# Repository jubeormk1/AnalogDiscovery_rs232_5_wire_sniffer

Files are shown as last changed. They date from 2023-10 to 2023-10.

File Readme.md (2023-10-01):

# Analog Discovery RS-232 five wire sniffer add on circuit
## Motivation
While troubleshooting an old but extremely robust threadmill, I came across an RS-232 data link between the device and its master computer. Since I do not have any instruments to sniff the messages flowing through a RS-232 link, I decided to build an extension board to add this capability to my Analog Discovery II instrument (AD). To give myself more flexibility, I am adding plenty of headers to monitor extra signal lines in addition to the main RxD and TxD. A total of five lines can be monitored at any time.

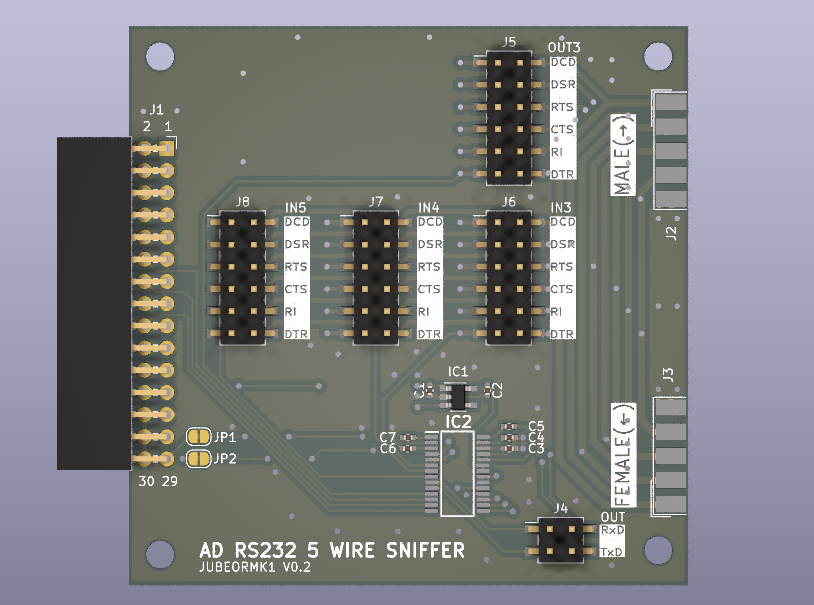
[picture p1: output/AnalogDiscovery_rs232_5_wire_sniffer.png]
Board render

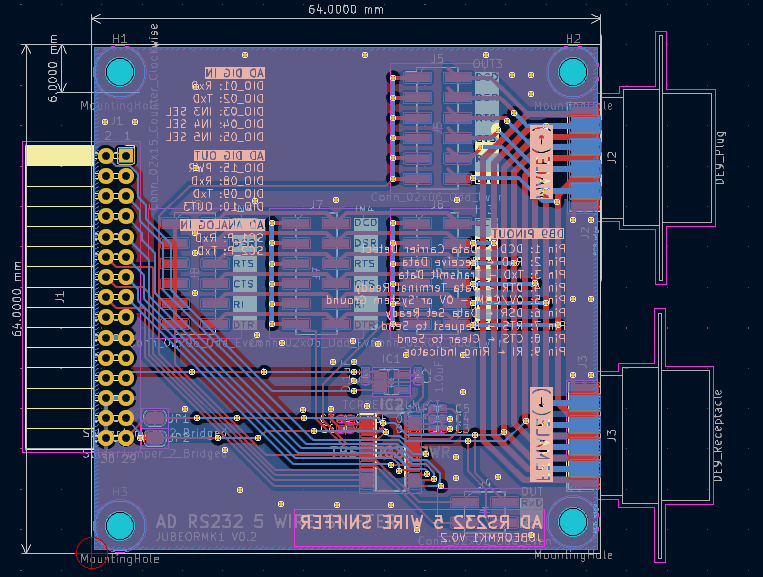
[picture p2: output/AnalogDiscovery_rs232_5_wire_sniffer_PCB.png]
PCB screenshot


## Warnings
Use it at your own risk. I take no responsibility for any damage caused to any device attached to this board. Since this is an experimental circuit, I assume that whoever is reading this is a tinker and has basic skills dealing with extra-low-voltage circuits.

## Features
* Uses the [Texas Instrument TRSF3243EIPWR Multichannel RS-232 compatible line driver/receiver](https://www.ti.com/product/TRSF3243E)
* Five channel RS-232 sniffer
* Passthrough DB9 Male to DB9 female
* RxD and TxD lines always connected to AD instrument ``DIO[0:1]``
* Selectable signals can be connected to the AD ``DIO[2:4]`` via header shunt pins
* RxD and TxD signals connected to AD instrument oscilloscope channels
* Optionally, RxD and TxD can be driven by an AD instrument using ``DIO[8:9]``
* It is also possible to select one more signal line to be driven by an AD instrument ``DIO[10]``
* The driver power can be enable(disable) driving the ``DIO[15]`` high(low)

## Required equipment:
* A data link with RS-232 communication to sniff on
* Personal Computer
* Digilent Analog Discovery (R) Instrument
* Software Digilent Waveforms(R)
* Some extra db9 terminated cables to make the connections

## License

Analog Discovery (R) and Waveforms(R) are Digilent trademarks.
The license is described in the file 'LICENSE'.

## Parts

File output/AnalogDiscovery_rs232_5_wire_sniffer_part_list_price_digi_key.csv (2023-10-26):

Index | Quantity | Part Number | Manufacturer Part Number | Description | Customer Reference | Available | Backorder | Unit Price | Extended Price AUD
1 | 5 | 296-TRSF3243EIPWRCT-ND | TRSF3243EIPWR | IC TRANSCEIVER FULL 3/5 28TSSOP |  | 5 | 0 | 4.64000 | 23.20
2 | 10 | TCR2EF33LM(CTCT-ND | TCR2EF33,LM(CT | IC REG LINEAR 3.3V 200MA SMV |  | 10 | 0 | 0.39300 | 3.93
3 | 100 | 478-KGM05AR71C104KHCT-ND | KGM05AR71C104KH | CAP CER 0.1UF 16V X7R 0402 |  | 100 | 0 | 0.00990 | 0.99
4 | 6 | 718-1719-1-ND | 298D105X0010K2T | CAP TANT 1UF 20% 10V 0402 |  | 6 | 0 | 2.61000 | 15.66
5 | 6 | AE11063-ND | A-DF 09 LL/Z | CONN D-SUB RCPT 9POS SLDR CUP |  | 6 | 0 | 0.84000 | 5.04
6 | 6 | AE10972-ND | A-DS 09 LL/Z | CONN D-SUB PLUG 9POS SLDR CUP |  | 6 | 0 | 0.84000 | 5.04
7 | 6 | 4324-PHDD-SS004G1ABOGE-B005CT-ND | PHDD-SS004G1ABOGE-B005 | MALE HEADER VERTICAL SMD 4POS G/ |  | 6 | 0 | 0.47000 | 2.82
8 | 22 | 4324-PHDD-SS016G1ABOGE-B005CT-ND | PHDD-SS016G1ABOGE-B005 | MALE HEADER VERTICAL SMD 16POS G |  | 22 | 0 | 0.78000 | 17.16
9 | 30 | S9341-ND | NPC02SXON-RC | CONN JUMPER SHORTING .100" GOLD |  | 30 | 0 | 0.11440 | 3.43

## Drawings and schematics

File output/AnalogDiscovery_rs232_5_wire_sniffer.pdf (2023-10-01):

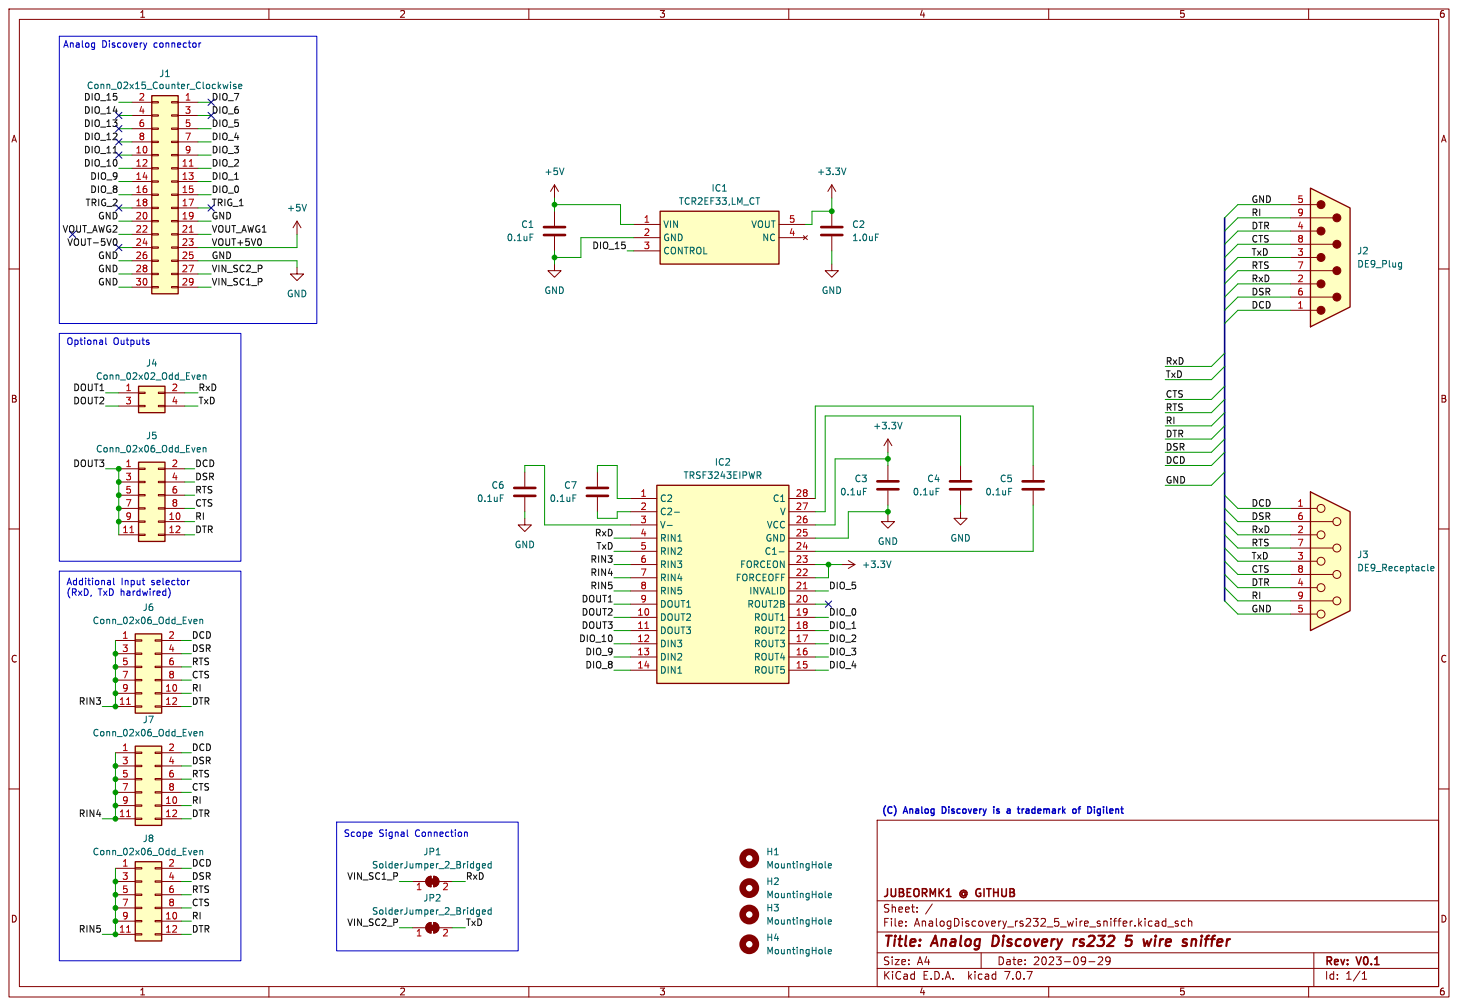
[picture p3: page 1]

CTS GND GND GND GND

(C) Analog Discovery is a trademark of Digilent

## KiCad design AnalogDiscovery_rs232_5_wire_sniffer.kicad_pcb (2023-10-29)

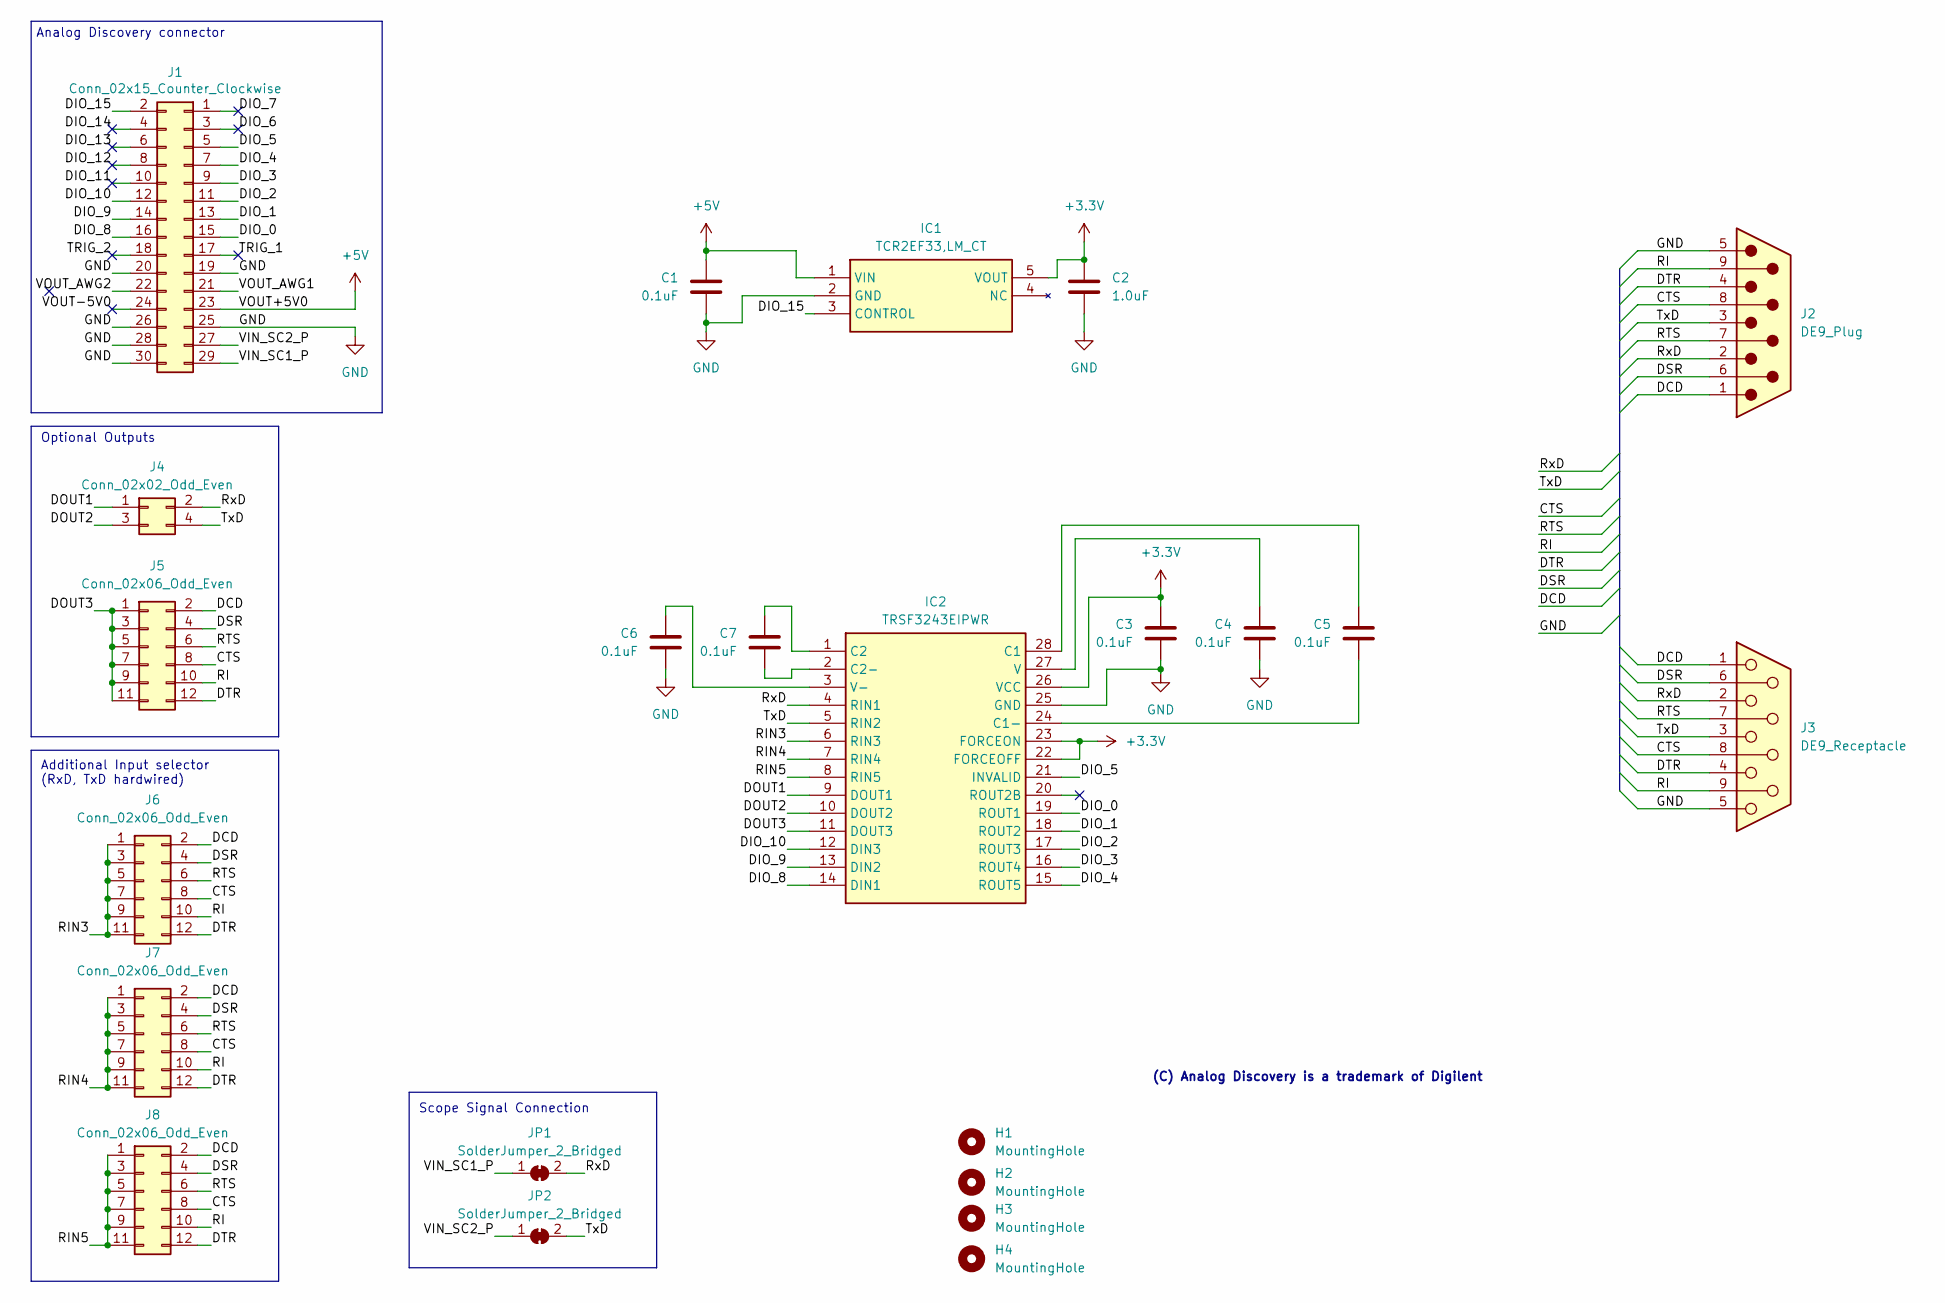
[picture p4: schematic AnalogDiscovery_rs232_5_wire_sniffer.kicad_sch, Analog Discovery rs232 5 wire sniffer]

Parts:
C1, C3, C4, C5, C6, C7: 0.1uF; C_0402_1005Metric_Pad0.74x0.62mm_HandSolder; Manufacturer_Part_Number KGM05AR71C103KH
C2: 1.0uF; C_0603_1608Metric_Pad1.08x0.95mm_HandSolder; Manufacturer_Part_Number KGM05AR71C104KH
H1, H2, H3, H4: MountingHole; MountingHole_3.2mm_M3
IC1: TCR2EF33,LM_CT; SOT-23-5_HandSoldering; Manufacturer_Part_Number TCR2EF33,LM(CT; Mouser Part Number 757-TCR2EF33LMCT
IC2: TRSF3243EIPWR; SOP65P640X120-28N; Manufacturer_Part_Number TRSF3243EIPWR; Mouser Part Number 595-TRSF3243EIPWR
J1: Conn_02x15_Counter_Clockwise; PinSocket_2x15_P2.54mm_Horizontal
J2: DE9_Plug; DSUB-9_Female_EdgeMount_P2.77mm
J3: DE9_Receptacle; DSUB-9_Male_EdgeMount_P2.77mm
J4: Conn_02x02_Odd_Even; PinHeader_2x02_P2.54mm_Vertical_SMD
J5, J6, J7, J8: Conn_02x06_Odd_Even; PinHeader_2x06_P2.54mm_Vertical_SMD
JP1, JP2: SolderJumper_2_Bridged; SolderJumper-2_P1.3mm_Bridged_RoundedPad1.0x1.5mm

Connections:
+3.3V: C2.1, C3.2, IC1.5 (VOUT), IC2.22 (FORCEOFF), IC2.23 (FORCEON), IC2.26 (VCC)
+5V: C1.2, IC1.1 (VIN), J1.23
/CTS: J2.8, J3.8, J5.8, J6.8, J7.8, J8.8
/DCD: J2.1, J3.1, J5.2, J6.2, J7.2, J8.2
/DIO_0: IC2.19 (ROUT1), J1.15
/DIO_1: IC2.18 (ROUT2), J1.13
/DIO_2: IC2.17 (ROUT3), J1.11
/DIO_3: IC2.16 (ROUT4), J1.9
/DIO_4: IC2.15 (ROUT5), J1.7
/DIO_5: IC2.21 (INVALID), J1.5
/DIO_6: J1.3
/DIO_7: J1.1
/DIO_8: IC2.14 (DIN1), J1.16
/DIO_9: IC2.13 (DIN2), J1.14
/DIO_10: IC2.12 (DIN3), J1.12
/DIO_11: J1.10
/DIO_12: J1.8
/DIO_13: J1.6
/DIO_14: J1.4
/DIO_15: IC1.3 (CONTROL), J1.2
/DOUT1: IC2.9 (DOUT1), J4.1
/DOUT2: IC2.10 (DOUT2), J4.3
/DOUT3: IC2.11 (DOUT3), J5.1, J5.3, J5.5, J5.7, J5.9, J5.11
/DSR: J2.6, J3.6, J5.4, J6.4, J7.4, J8.4
/DTR: J2.4, J3.4, J5.12, J6.12, J7.12, J8.12
/RI: J2.9, J3.9, J5.10, J6.10, J7.10, J8.10
/RIN3: IC2.6 (RIN3), J6.1, J6.3, J6.5, J6.7, J6.9, J6.11
/RIN4: IC2.7 (RIN4), J7.1, J7.3, J7.5, J7.7, J7.9, J7.11
/RIN5: IC2.8 (RIN5), J8.1, J8.3, J8.5, J8.7, J8.9, J8.11
/RTS: J2.7, J3.7, J5.6, J6.6, J7.6, J8.6
/RxD: IC2.4 (RIN1), J2.2, J3.2, J4.2, JP1.2 (B)
/TRIG_1: J1.17
/TRIG_2: J1.18
/TxD: IC2.5 (RIN2), J2.3, J3.3, J4.4, JP2.2 (B)
/VIN_SC1_P: J1.29, JP1.1 (A)
/VIN_SC2_P: J1.27, JP2.1 (A)
/VOUT-5V0: J1.24
/VOUT_AWG1: J1.21
/VOUT_AWG2: J1.22
GND: C1.1, C2.2, C3.1, C4.1, C6.1, IC1.2 (GND), IC2.25 (GND), J1.19, J1.20, J1.25, J1.26, J1.28, J1.30, J2.5, J3.5
unnamed: C5.2, IC2.28 (C1)
unnamed: C5.1, IC2.24 (C1-)
unnamed: C7.2, IC2.1 (C2)
unnamed: C7.1, IC2.2 (C2-)
unnamed: C4.2, IC2.27 (V)
unnamed: C6.2, IC2.3 (V-)

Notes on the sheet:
Scope Signal Connection
Analog Discovery connector
Optional Outputs
Additional Input selector (RxD, TxD hardwired)
(C) Analog Discovery is a trademark of Digilent

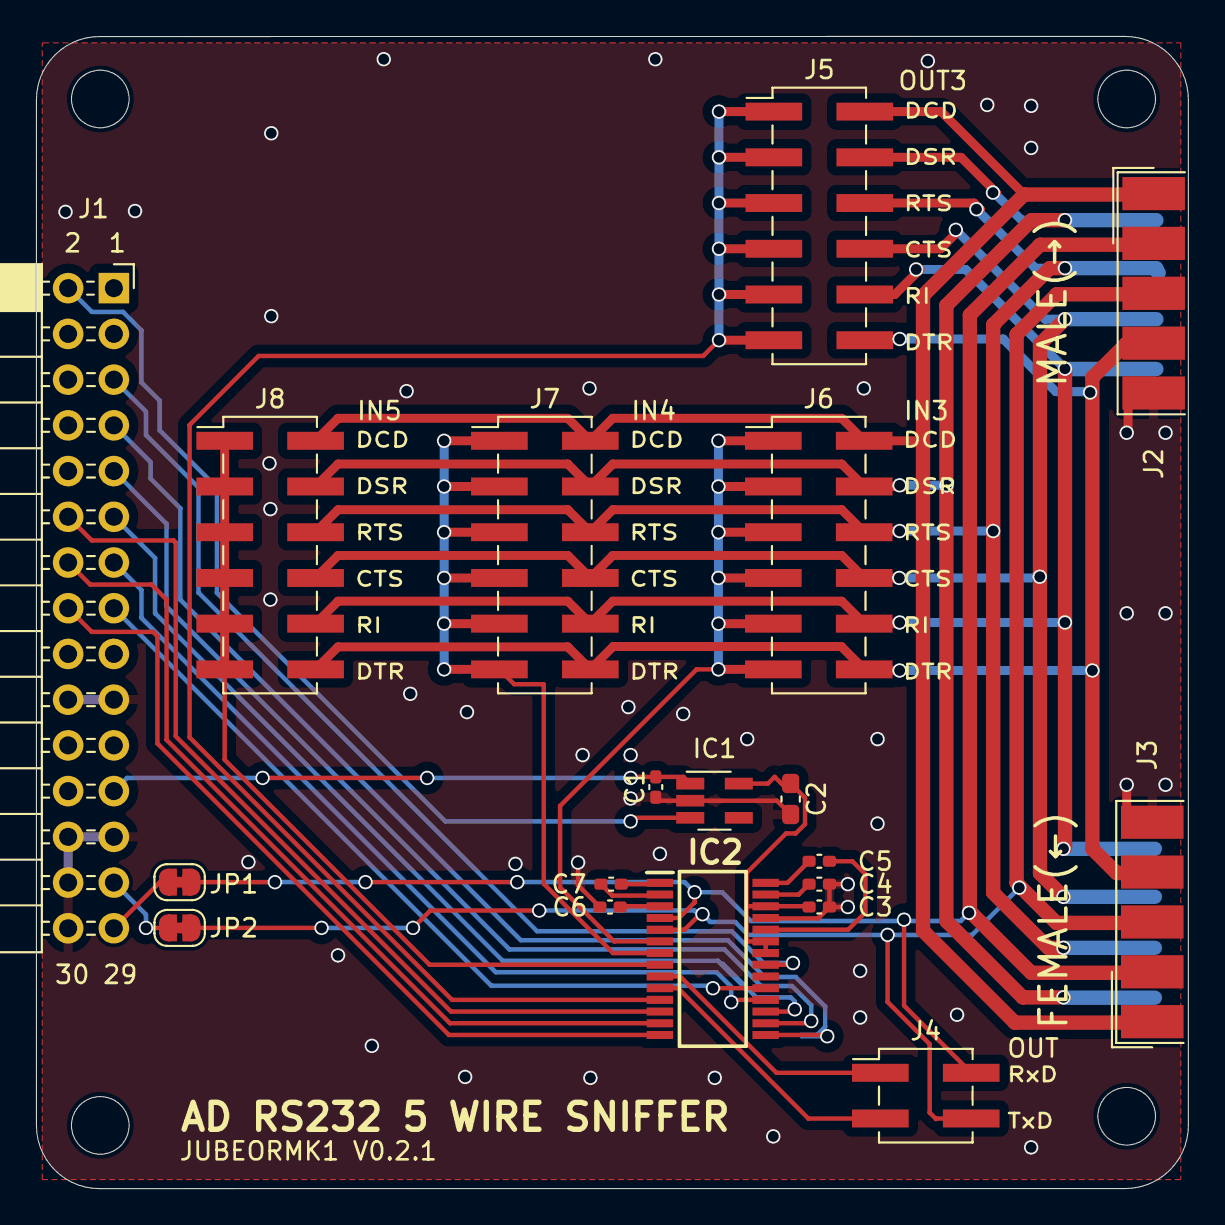
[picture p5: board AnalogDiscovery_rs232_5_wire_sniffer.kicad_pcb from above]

Board: 2 copper layers, 64.0 x 64.0 mm, 23 parts (0 on the bottom side), 35 nets.

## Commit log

2023-10-01 first upload V0.1
    [AnalogDiscovery_rs232_5_wire_sniffer-B_Cu.gbr, AnalogDiscovery_rs232_5_wire_sniffer-B_Mask.gbr, AnalogDiscovery_rs232_5_wire_sniffer-B_Silkscreen.gbr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]
2023-10-01 cropped board render
2023-10-01 Update Readme.md
    Adding a quick board render.
2023-10-01 V0.2
    Silkscreen changes
    [AnalogDiscovery_rs232_5_wire_sniffer.kicad_pcb]
2023-10-26 Added DigiKey part list
    [AnalogDiscovery_rs232_5_wire_sniffer.kicad_sch, AnalogDiscovery_rs232_5_wire_sniffer_part_list_price_digi_key.csv]
2023-10-29 New revision V0.2.1
    Small changes:
    - Rounded board edges
    - better annotation
    - C2 is 0603 instead of 0402
    - Missing tracks have been removed in J5
    [AnalogDiscovery_rs232_5_wire_sniffer-B_Cu.gbr, AnalogDiscovery_rs232_5_wire_sniffer-B_Mask.gbr, AnalogDiscovery_rs232_5_wire_sniffer-B_Silkscreen.gbr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]
